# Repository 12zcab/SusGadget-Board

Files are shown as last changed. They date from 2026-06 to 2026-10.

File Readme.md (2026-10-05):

## SusGadget

IMG_20260813_192945 (2)
A hack ducky which can maybe do some questionable stuff to your computer or maybe it’s just a sweet little game who knows!
<br>
<br>

## Table of contents
- [Zine page](#Zine)
- [Images](#Images)
- [What is this](#What-is-this)
- [Why I made this](#Why-I-made-this)
- [Parts required](#Parts-required)
- [How to make it yourself](#How-to-make-it-yourself)

<br>
<br>
Huge thanks to Raghav who helped me polish the project and improved many design flaws and zine design :) 

## Zine
Zine

## Youtube Demo

[Watch here!](https://youtu.be/1S0NnBTiFww?si=1X6zqkv0NfYqutrI)

## Images

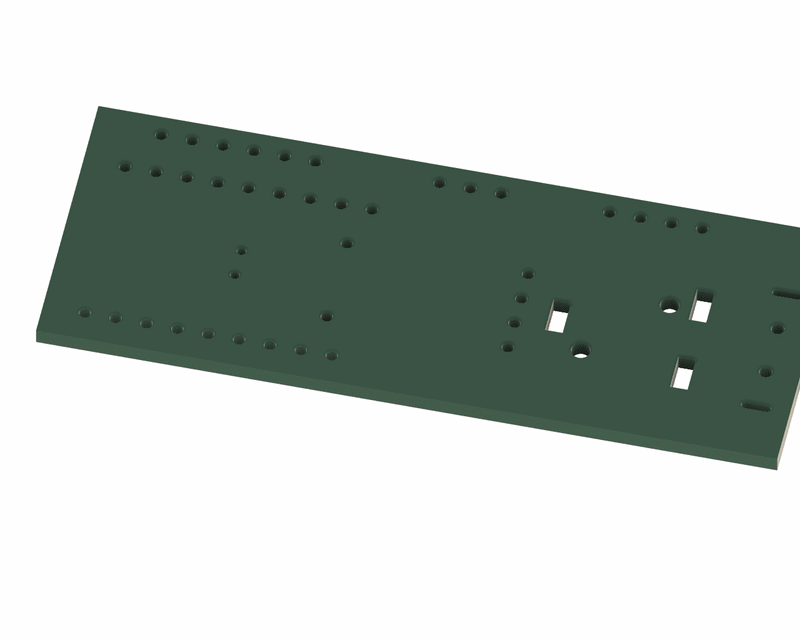
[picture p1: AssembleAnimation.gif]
Assemble







design (1)
pcbf
routing (1)

<br>
<br>

## What is this

This is a esp32 S3 supermini based Hackducky, with an OLED display, a joystick and a potentiometer which can be used to execute commands on your friend's computer to prank them or maybe just it as a mini display for timers, temperatures or any other stats, the possibilities are endless! !
it also has a potentiometer and a buzzer so u can may be make some weird beep noise that changes its pitch while u spin the potentiometer and communicate with aliens (welp, who knows?)
Definitely a cool gadget and definitely sus enough :D
<br>
<br>

## Why I made this :|
Humm idk this is like what people think electronic nerds will make : |
(Actually i wanna try to plug in this usb and tell my friend this is just a oled small screen to monitor his computer's temperature then shutdown his computer with Alt+F4+Enter while he plays Roblox :DDDDD)

## Parts required
 1. A 0.91 inch Oled for Display
 2. A Potentiometer for Analog Input
 3. A Joystick Module Connecter
 4. A RGB WS2812 LED on board
 5. A USB-A with CH340 on board serial interface (and for power)
 6. Extend IO Ports (GPIO,I2C)
 7. 5-Way Joy-Stick like Switch
 8. a buzzer :D

## How to make it yourself
 <h3> 1. Acquire parts </h3>
- Navigate to the BOM in the repository and buy the listed parts. <br>
- 3D print the case by acquiring stl files from the 3de print folder in the repository. <br>
- Order PCB by using the gerber files provided in the repository. <br>
 
 <h3> 2. Assembly </h3>
 - Solder all the components on the PCB. <br>
 - Put the soldered PCB in the case. <br>
  
 <h3> 3. Firmware setup </h3>

 - Connect your device to the esp 32 <br>
 - Download the firmware files from the repo <br>
 - Load the firmware <br>

<h3> 4. (most imp step) </h3>
- prank your friends <br>
- have fun  <br>

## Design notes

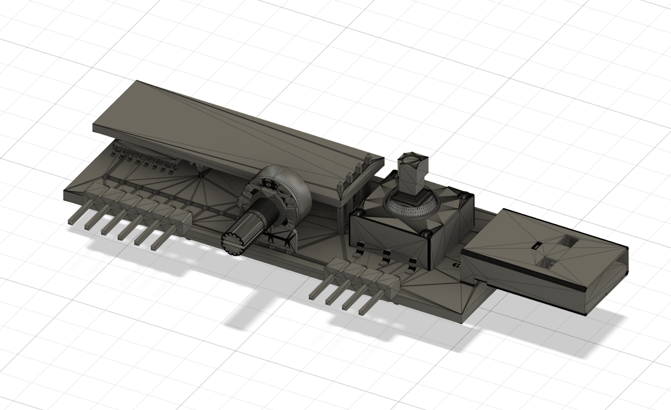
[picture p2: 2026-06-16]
Images/3Ddesign.png

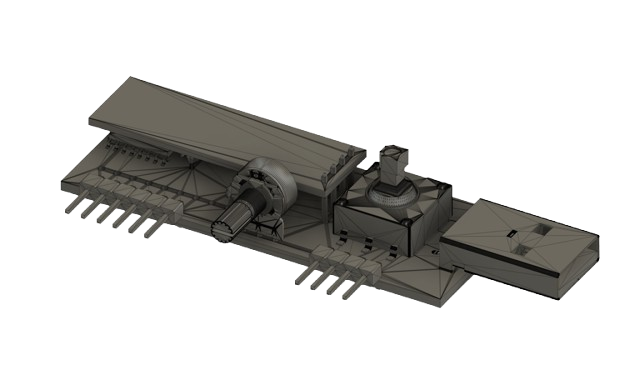
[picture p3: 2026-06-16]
Images/3Ddesign-removebg-preview.png

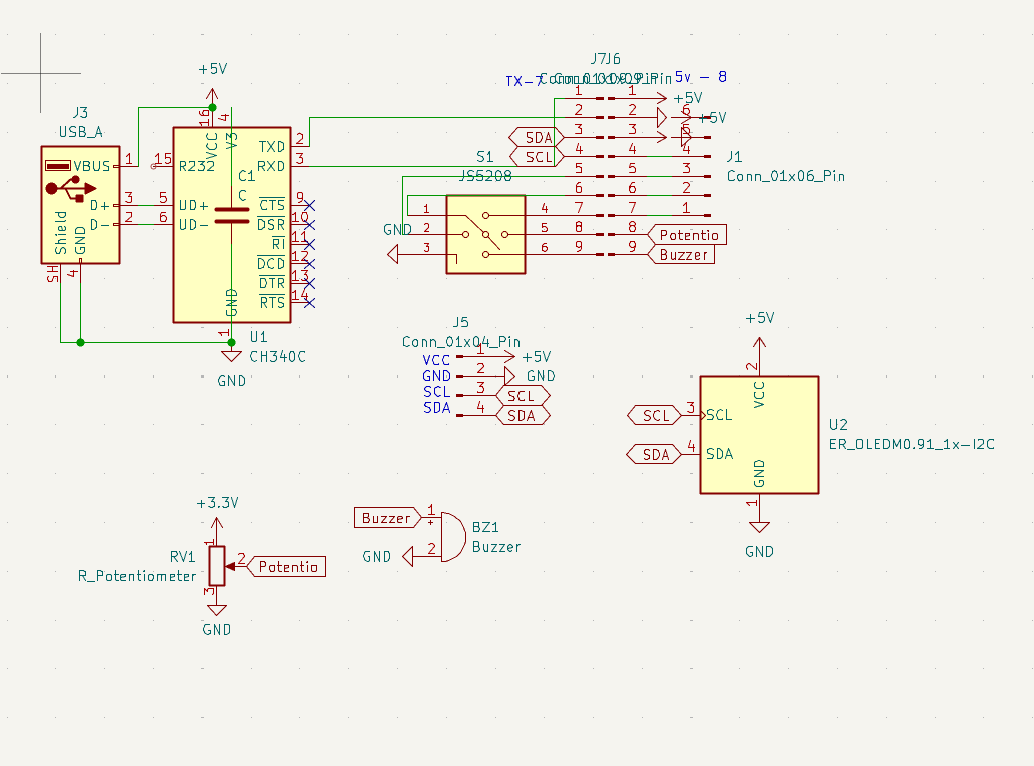
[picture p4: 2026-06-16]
Images/design (1).png

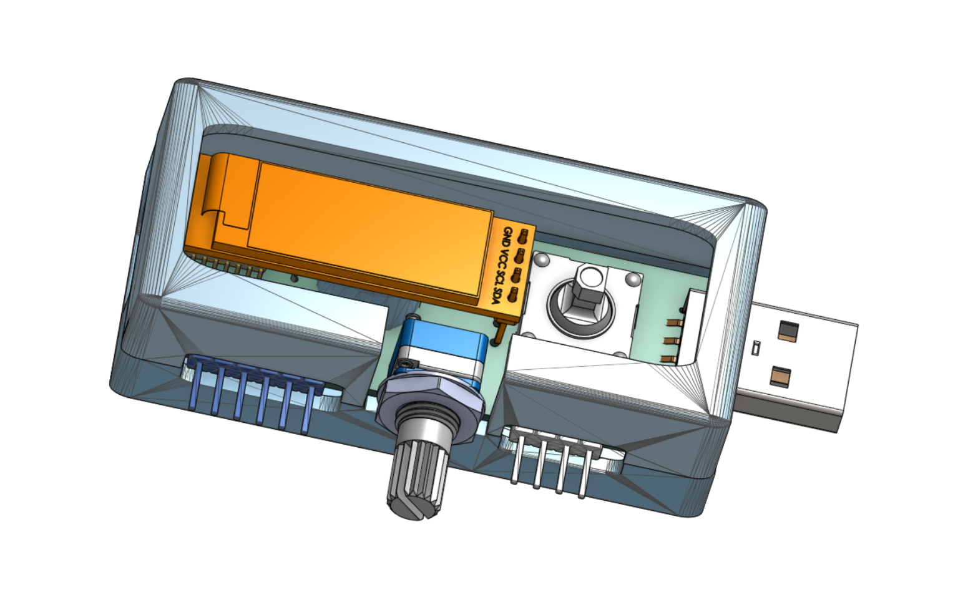
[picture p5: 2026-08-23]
Images/Screenshot 2026-08-23 152553.png

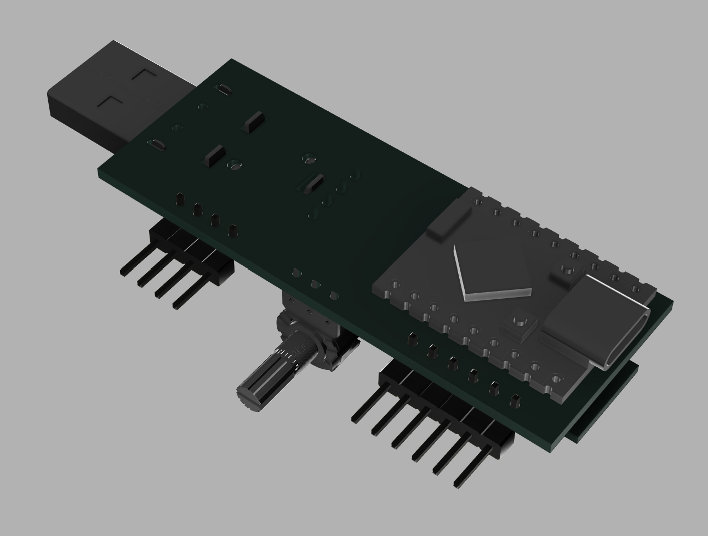
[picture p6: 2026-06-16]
Images/3DB.png

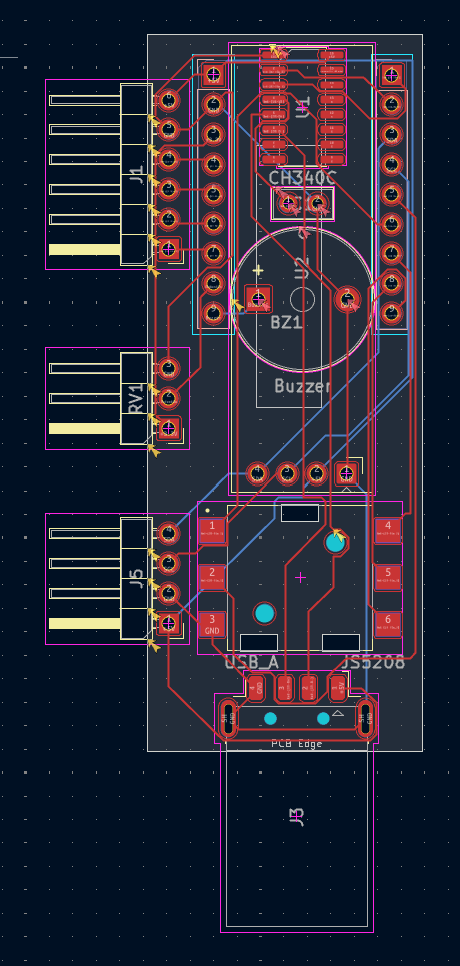
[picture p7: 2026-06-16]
Images/routing (1).png

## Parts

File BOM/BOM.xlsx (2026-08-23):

Name | Link | Quantity | QT Price | RMBPrice | USDPrice
ESP32 S3 Supermini | https://item.taobao.com/item.htm?id=980496057690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 | 1 | 14.9 | 14.9 | 2.235
JS5208 | https://item.taobao.com/item.htm?id=739043147728 | 1 | 2.2 | 2.2 | 0.33
104 Capacitor | https://detail.tmall.com/item.htm?ali_trackid=318_c9a42c10e288c0737574497ed4e334d1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 | 1 | Negligible | Negligible | 0
I2C Oled 0.91inch | https://item.taobao.com/item.htm?id=799718292351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 | 1 | 8 | 8 | 1.2
Potentiometer | https://detail.tmall.com/item.htm?id=611352518150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 | 1 | 5.5 | 5.5 | 0.825
USB-A Male SMD | https://item.taobao.com/item.htm?id=1003164355210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 | 1 | 2.19 | 2.19 | 0.3285
CH340C | https://item.taobao.com/item.htm?id=572355836370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 | 1 | 2.31 | 2.31 | 0.3465
Estimated PCB cost |  |  |  |  | 10
Including PinHeaders and PinSocket |  |  |  |  | 0.5
Also USB Convertors are required(Not Essential) |  |  |  |  | 0
Sum Up |  |  |  |  | 15.765

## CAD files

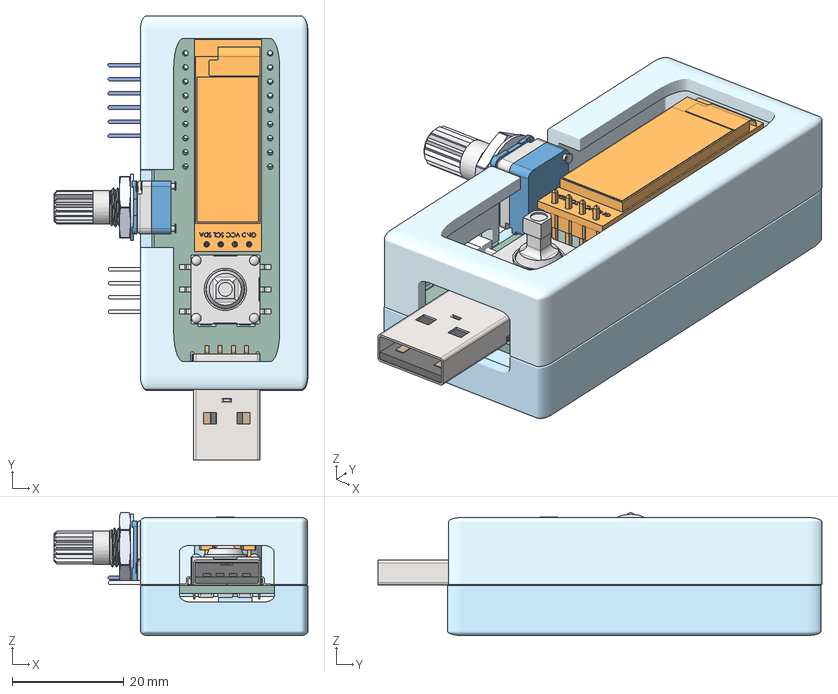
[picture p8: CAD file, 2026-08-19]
3D/Final_assembly_sus_gadget.step
45.5 x 79.6 x 22.1 mm
RK097x-Base-Rivets-ShaftKC x 6
susGadget_PCB
Ressalto-extrus�o10
Cut-Extrude15
RK097x-Housing1 x 4
RK097x-Cover

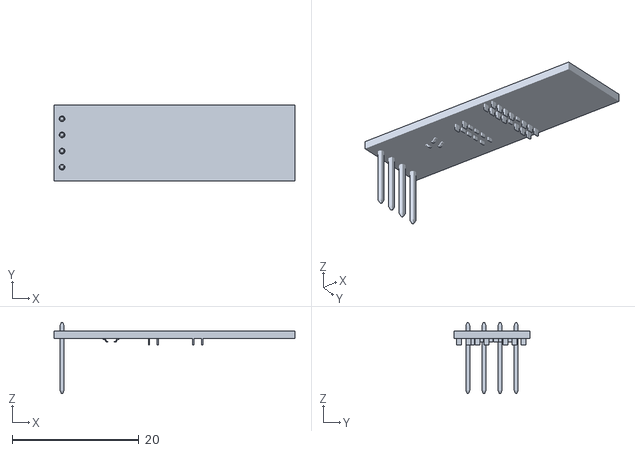
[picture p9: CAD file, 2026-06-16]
3D/OLED 128 x 32 Display Assembly.stl
38.0 x 12.0 x 11.2

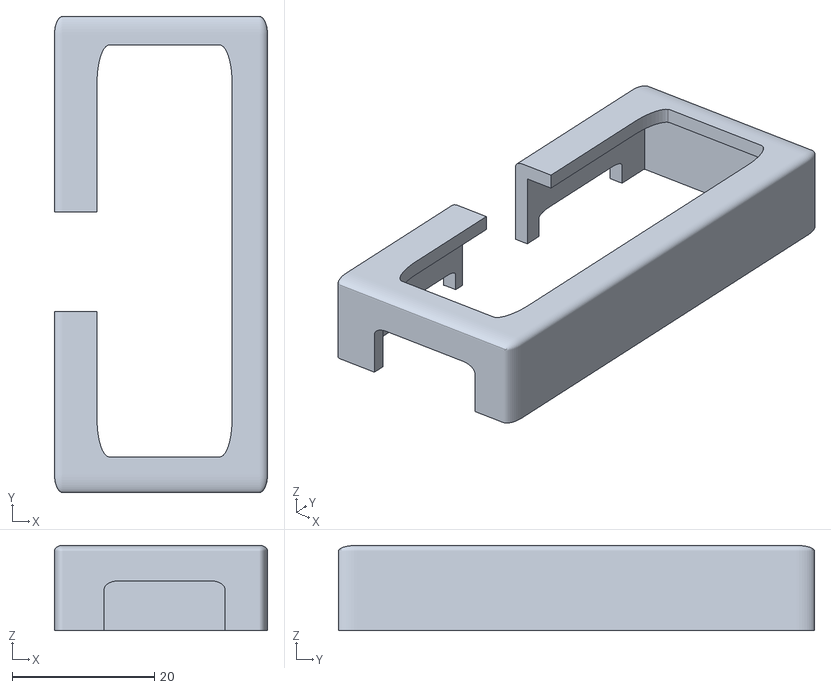
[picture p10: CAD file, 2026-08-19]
3D/NewUp.stl
30.0 x 67.0 x 12.0

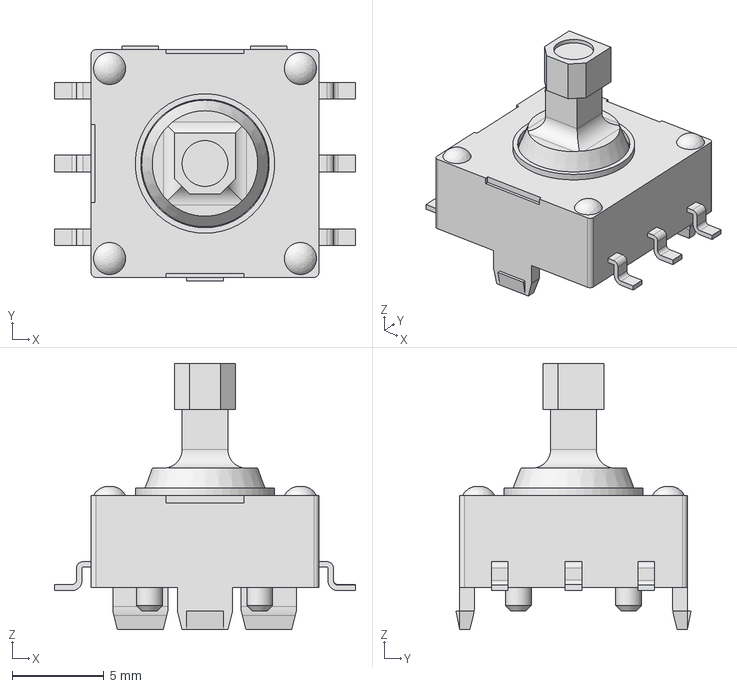
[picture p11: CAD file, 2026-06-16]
JS5208/JS5208.step
16.4 x 12.8 x 14.5 mm

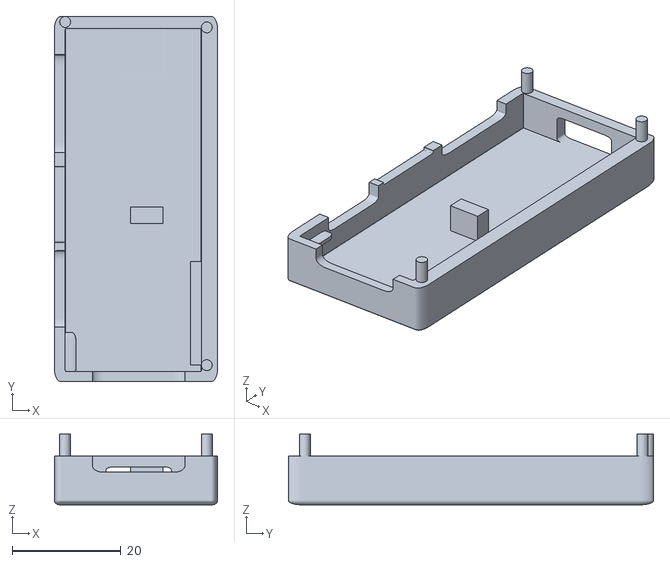
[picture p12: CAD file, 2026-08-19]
3D/NewBottom.stl
30.0 x 67.0 x 13.0

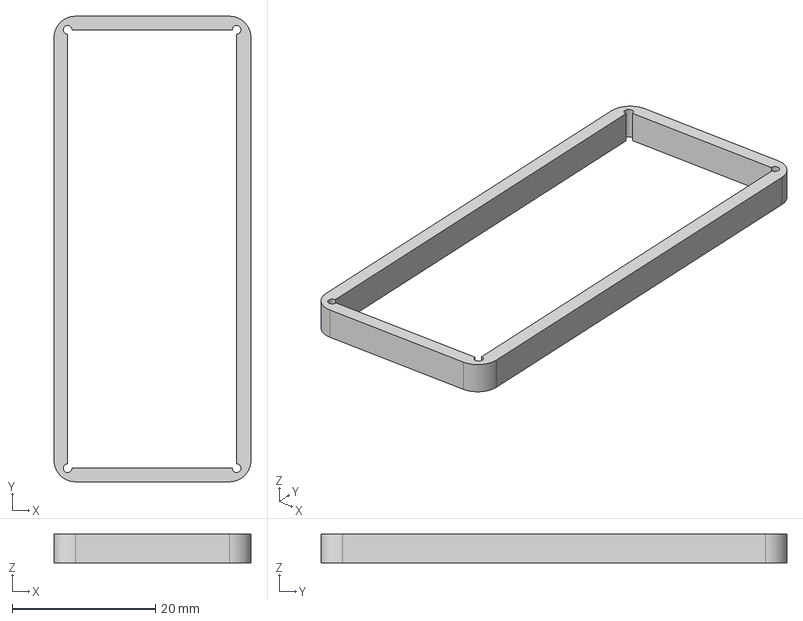
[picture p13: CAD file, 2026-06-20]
3D/CaseCap.step
27.5 x 65.0 x 4.00 mm

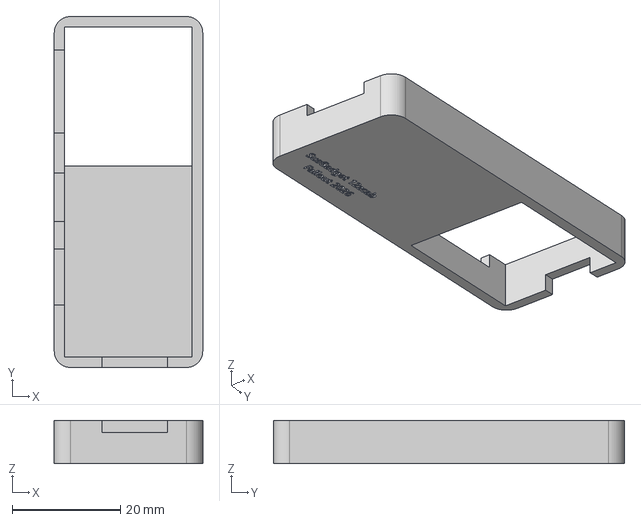
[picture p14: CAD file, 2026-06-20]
3D/Case.step
27.5 x 65.0 x 8.00 mm

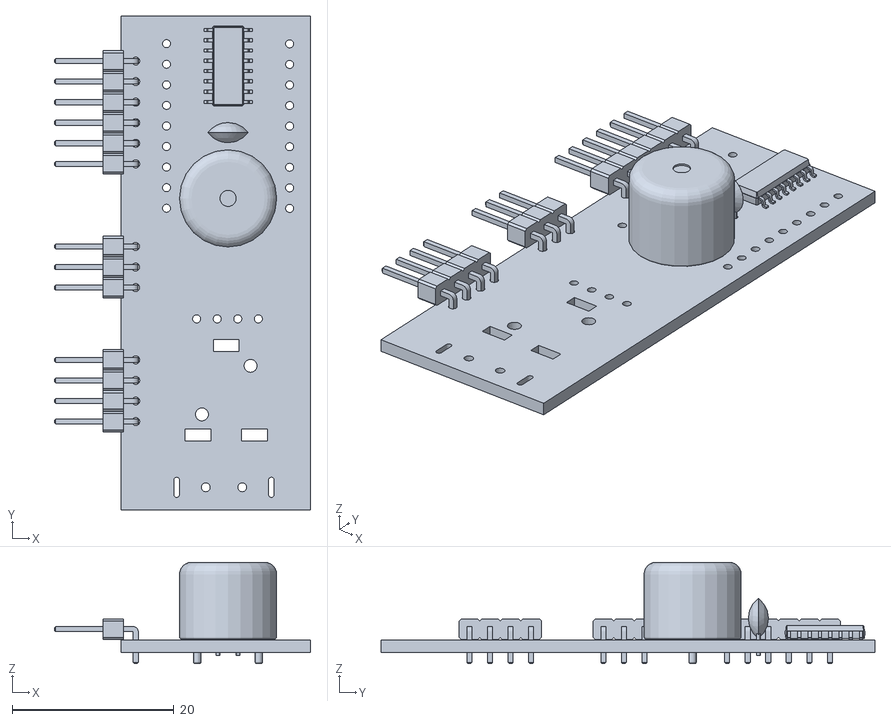
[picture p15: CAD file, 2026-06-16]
3D/pcb_with_com.stl
31.7 x 61.0 x 12.5

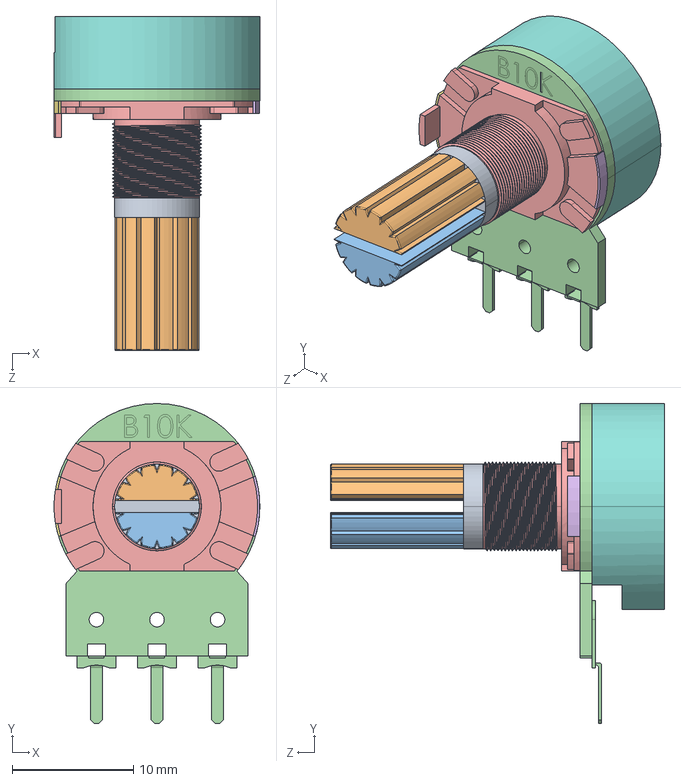
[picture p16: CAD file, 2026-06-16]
3D/PotentiometerB10K.STEP
17.0 x 26.4 x 27.6 mm

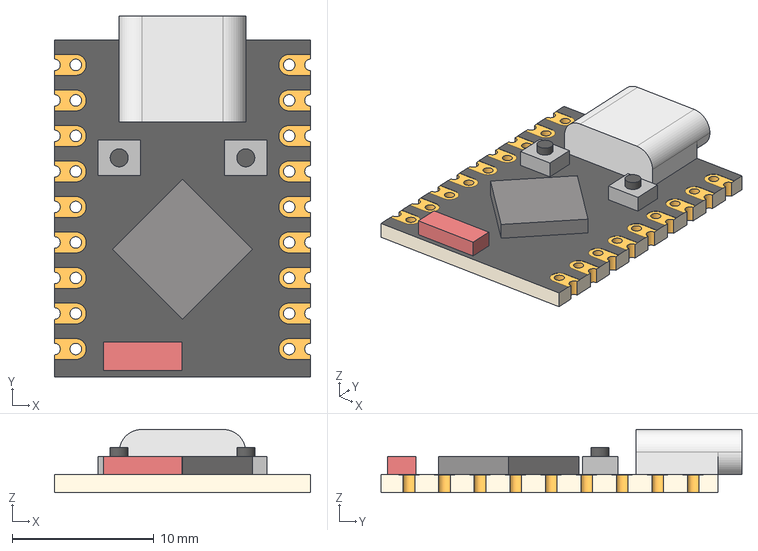
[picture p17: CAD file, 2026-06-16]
3D/ESP32S3 Super Mini.step
18.0 x 25.4 x 4.45 mm

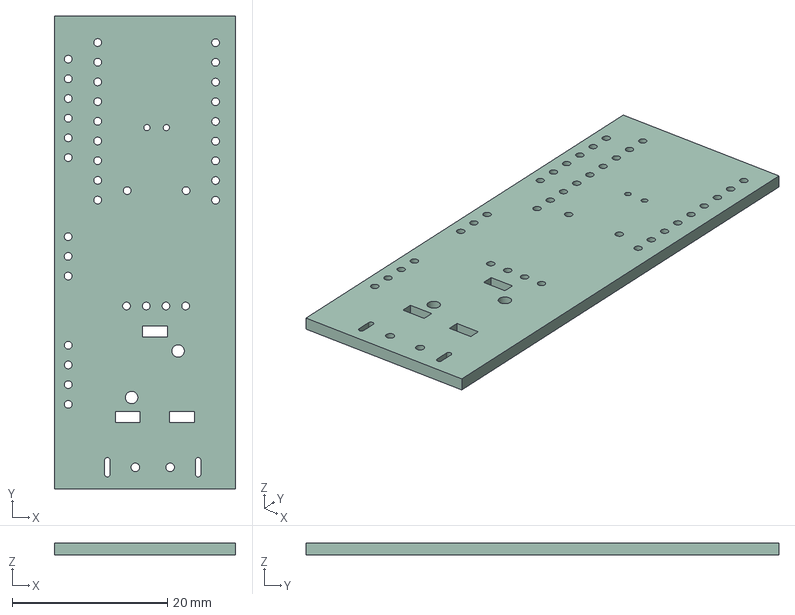
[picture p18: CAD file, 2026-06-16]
3D/pcb.step
23.4 x 61.0 x 1.51 mm

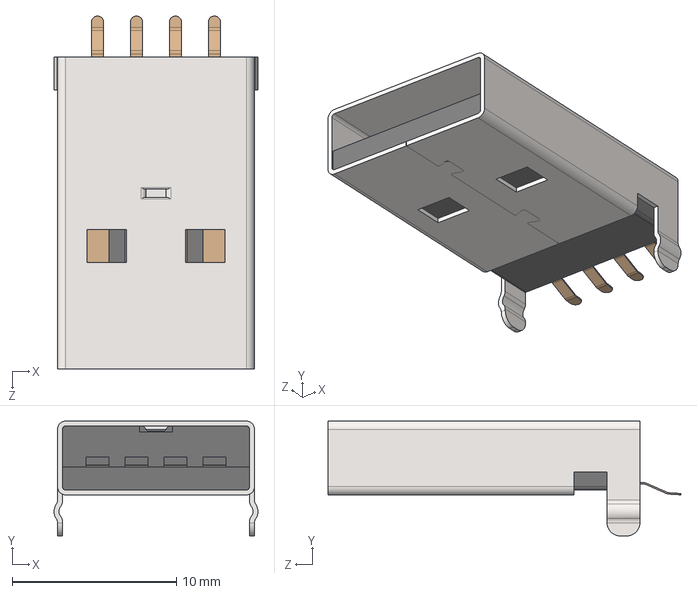
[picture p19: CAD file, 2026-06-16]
3D/USB Connector Type A male, SMT.STEP
12.4 x 7.00 x 21.5 mm

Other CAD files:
3D/ESP32S3 Super Mini.stl
3D/JS5208.stl
3D/PotentiometerB10K.stl
3D/USB Connector Type A male, SMT.stl
3D/pcb.stl

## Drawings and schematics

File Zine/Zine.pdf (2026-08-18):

# SUS GADGET

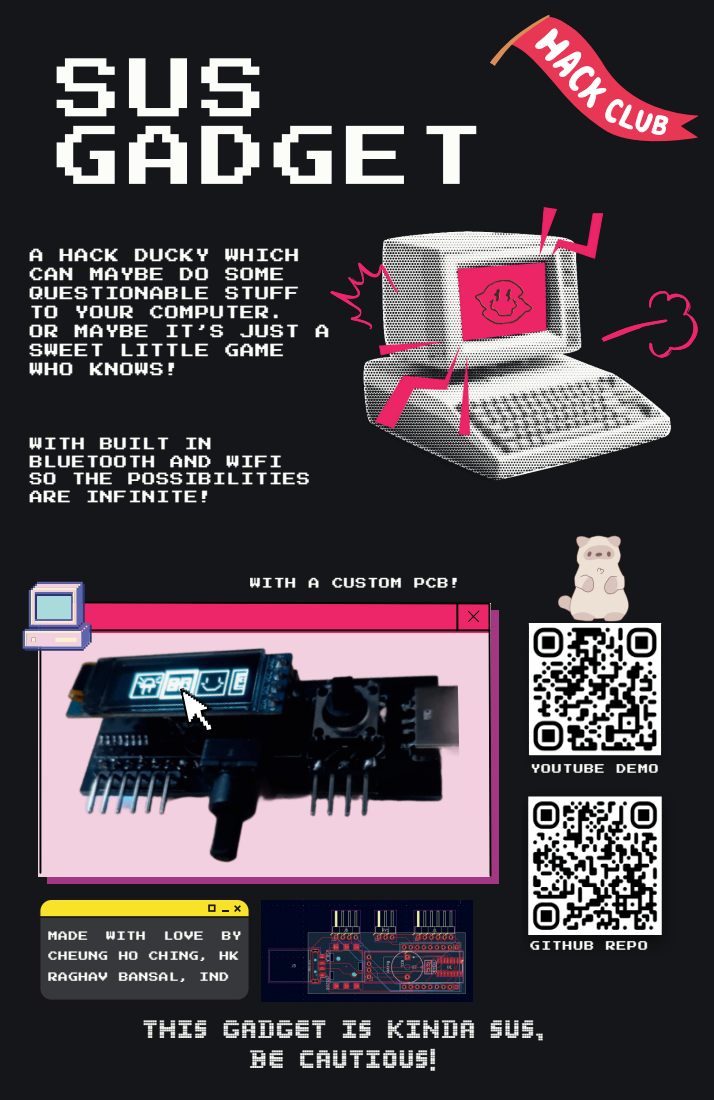
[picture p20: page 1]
YOUTUBE DEMO; GITHUB REPO; MADE; WITH; LOVE

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

WITH BUILT IN
BLUETOOTH AND WIFI
SO THE POSSIBILITIES
ARE INFINITE!

WITH A CUSTOM PCB!

CHEUNG HO CHING, HK
RAGHAV BANSAL, IND
This gadget is kinda sus,
be cautious!

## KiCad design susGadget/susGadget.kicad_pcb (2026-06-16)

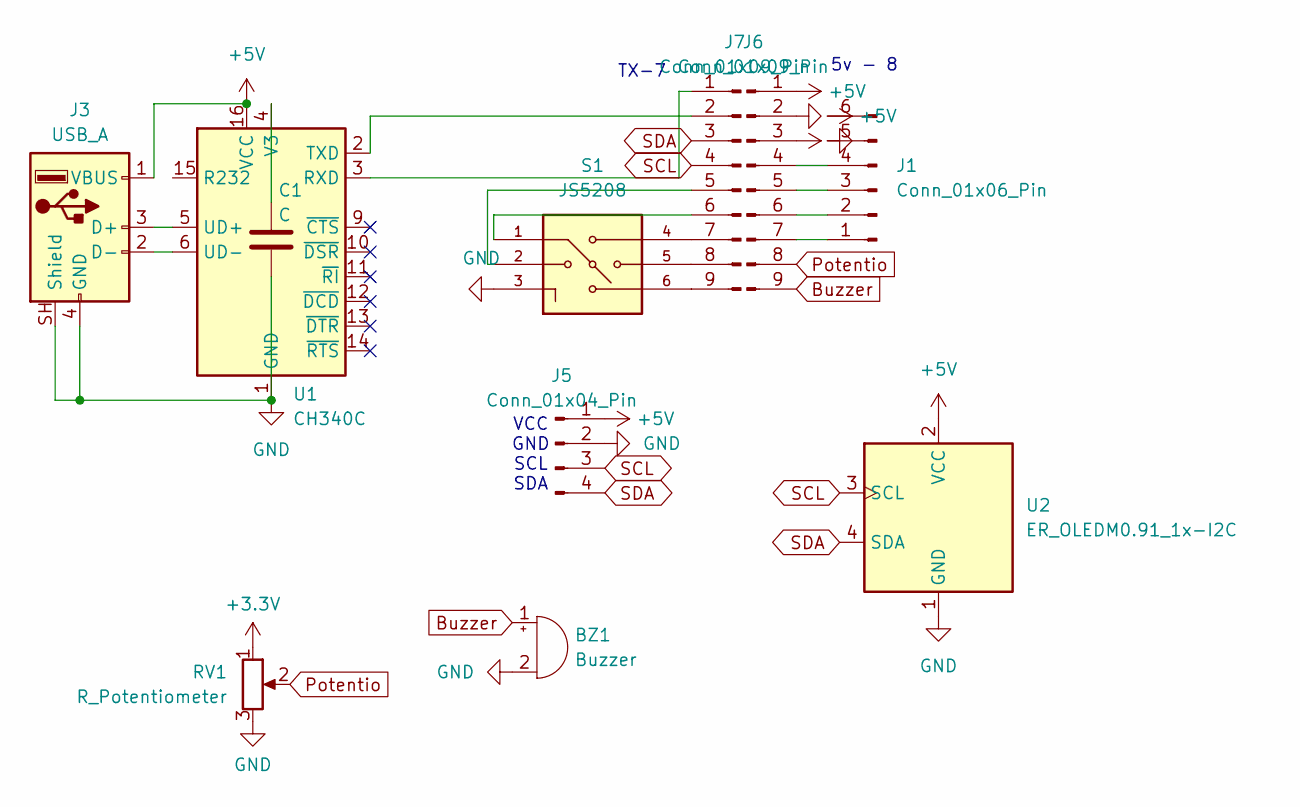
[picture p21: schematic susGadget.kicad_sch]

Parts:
BZ1: Buzzer; Buzzer_12x9.5RM7.6
C1: C; C_Disc_D5.0mm_W2.5mm_P2.50mm
J1: Conn_01x06_Pin; PinHeader_1x06_P2.54mm_Horizontal
J3: USB_A; USB_A_Molex_48037-2200_Horizontal
J5: Conn_01x04_Pin; PinHeader_1x04_P2.54mm_Horizontal
J6, J7: Conn_01x09_Pin; PinSocket_1x09_P2.54mm_Vertical
RV1: R_Potentiometer; PinHeader_1x03_P2.54mm_Horizontal
S1: JS5208; SW_JS5208; PARTREV D
U1: CH340C; SOIC-16_3.9x9.9mm_P1.27mm
U2: ER_OLEDM0.91_1x-I2C

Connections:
+3.3V: J6.3, RV1.1
+5V: J1.6, J3.1 (VBUS), J5.1, J6.1, U1.16 (VCC), U2.2 (VCC)
Buzzer: BZ1.1 (+), J6.9
GND: BZ1.2 (-), C1.2, J1.5, J3.4 (GND), J3.SH (Shield), J5.2, J6.2, RV1.3, S1.3, U1.1 (GND), U2.1 (GND)
unnamed: J1.1, J6.7
unnamed: J1.2, J6.6
unnamed: J1.3, J6.5
unnamed: J1.4, J6.4
unnamed: J3.3 (D+), U1.5 (UD+)
unnamed: J3.2 (D-), U1.6 (UD-)
unnamed: J7.1, U1.3 (RXD)
unnamed: J7.2, U1.2 (TXD)
unnamed: J7.5, S1.2
unnamed: J7.6, S1.1
unnamed: J7.7, S1.4
unnamed: J7.8, S1.5
unnamed: J7.9, S1.6
unnamed: C1.1, U1.4 (V3)
Potentio: J6.8, RV1.2
SCL: J5.3, J7.4, U2.3 (SCL)
SDA: J5.4, J7.3, U2.4 (SDA)

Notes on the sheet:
TX-7
5v - 8
VCC GND SCL SDA

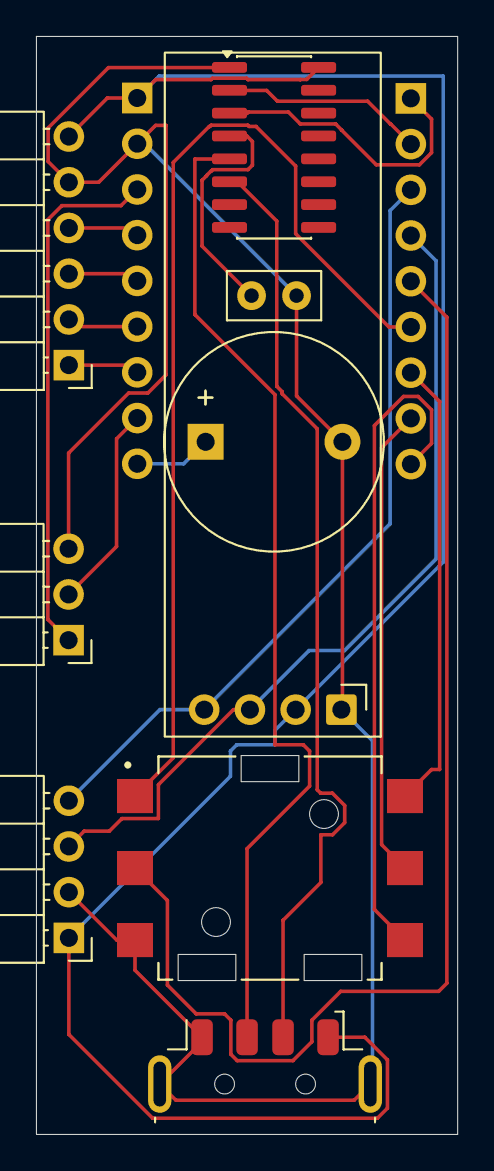
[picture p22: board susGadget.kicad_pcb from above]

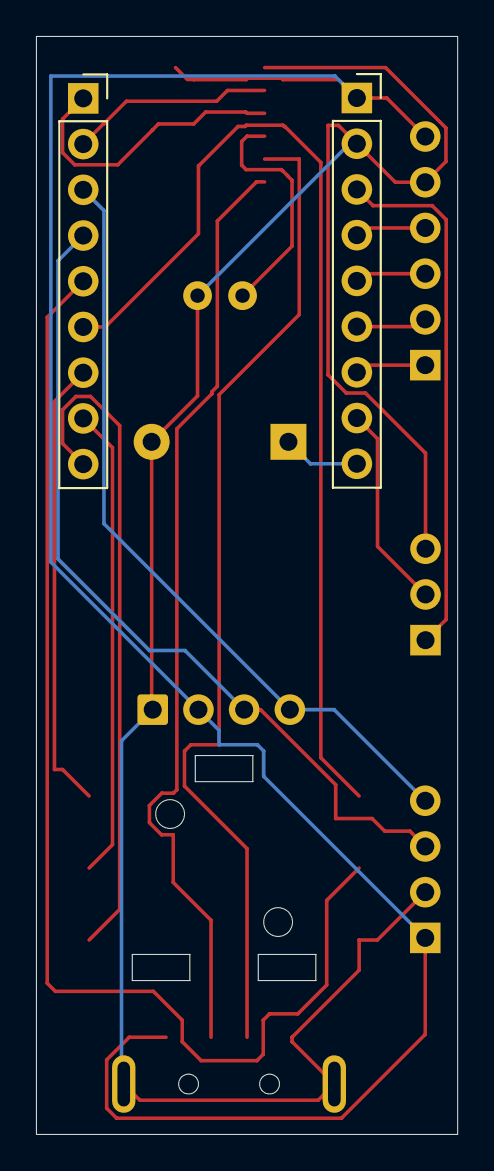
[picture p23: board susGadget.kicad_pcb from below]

Board: 2 copper layers, 23.4 x 61.0 mm, 11 parts (2 on the bottom side), 21 nets.

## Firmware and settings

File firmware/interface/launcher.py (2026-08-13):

import sys
import board
import digitalio
import re
def run_independent_app(app_path):
    print(f"[Launcher] Preparing Line-by-Line Sandbox (With Direct _end_ Check) for: {app_path}")
    
    try:
        with open(app_path, "r") as f:
            raw_code = f.read()
    except Exception:
        print(f"[Launcher] Error: Cannot find app at {app_path}")
        return

    function_text_injection = """
import board, digitalio, sys

def _Launcher_check_():
    try:
        with digitalio.DigitalInOut(board.IO0) as btn:
            btn.direction = digitalio.Direction.INPUT
            btn.pull = digitalio.Pull.UP
            if not btn.value:
                print("\\n[Launcher Check] Escape Button detected!")
                try:
                    if '_end_' in globals() or '_end_' in locals():
                        print("[Launcher Check] Directly calling App native _end_()...")
                        globals().get('_end_', locals().get('_end_'))()
                except Exception as ce:
                    print("[Launcher Check] App _end_() execution failed:", ce)
                raise KeyboardInterrupt("App terminated after direct end() call")
    except KeyboardInterrupt:
        raise
    except Exception:
        pass
"""

    loop_pattern = re.compile(r'^([ \t]*)(while|for)\s+(.+):')

    lines = raw_code.split('\n')
    modified_lines = []

    for line in lines:
        modified_lines.append(line)
        match = loop_pattern.match(line)
        if match:
            indent = match.group(1)
            modified_lines.append(f"{indent}    _Launcher_check_()")

    modified_code = '\n'.join(modified_lines)
    final_executable_code = function_text_injection + "\n" + modified_code

    print("[Launcher] Direct end() Call Injection Result:")
    print("----------------------------------------")
    print(final_executable_code)
    print("----------------------------------------")

    app_folder = "/".join(app_path.split("/")[:-1])
    if app_folder == "":
        app_folder = "/"

    if "/interface" not in sys.path:
        sys.path.append("/interface")

    path_was_added = False
    if app_folder not in sys.path:
        sys.path.insert(0, app_folder)
        path_was_added = True

    app_globals = {
        "__name__": "__main__",
        "__file__": app_path,
        "__path__": app_folder
    }

    try:
        exec(final_executable_code, app_globals)
        print("[Launcher] App finished execution naturally.")
    except KeyboardInterrupt:
        print("[Launcher] App successfully destroyed after direct exit cleanup.")
    except Exception as e:
        print(f"[Launcher] App crashed with error: {e}")
    finally:
        if path_was_added and app_folder in sys.path:
            sys.path.remove(app_folder)
            
        for key in list(sys.modules.keys()):
            try:
                mod = sys.modules[key]
                if hasattr(mod, '__file__') and mod.__file__ and app_folder in mod.__file__:
                    del sys.modules[key]
            except Exception:
                pass
                
        app_globals.clear()
        print("[Launcher] Sandbox cleaned. Back to launch.py GUI.\n")

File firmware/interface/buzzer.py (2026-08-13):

import time
import board
import pwmio
global buzzer
def init():
    global buzzer
    buzzer = pwmio.PWMOut(board.IO8, frequency=1000, duty_cycle=0, variable_frequency=True)
    print("Buzzer Initialized")
def play_tone(frequency, duration):
    global buzzer
    buzzer.frequency = frequency
    buzzer.duty_cycle = 32768
    time.sleep(duration)
    buzzer.duty_cycle = 0
def active():
    global buzzer
    buzzer.duty_cycle = 32768
def deactive():
    global buzzer
    buzzer.duty_cycle = 0
def freq(fre):
    global buzzer
    buzzer.frequency = fre
def play_series(frequencies, durations):
    for frequency,duration in zip(frequencies, durations):
        if frequency == 0:
            time.sleep(duration)
        else:
            play_tone(frequency,duration)
init()

#play_series([659, 622, 659, 622, 659, 494, 587, 523, 440, 0, 262, 330, 440, 494, 0, 330, 494, 523, 659], [0.3, 0.3, 0.3, 0.3, 0.3, 0.3, 0.3, 0.3, 0.6, 0.2, 0.3, 0.3, 0.3, 0.6, 0.2, 0.3, 0.3, 0.3, 0.6])
#hehe an easter egg
# 12zcab 4/Aug/2026 01:17a.m.

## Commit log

2026-08-19 Rename Fantastic Blorr-Migelo (1).stl to NewBottom.stl
    [NewBottom.stl]
2026-08-19 Rename topcase-sus (1).stl to NewUp.stl
    [NewUp.stl]
2026-08-23 Add BOM file with component details and pricing
2026-08-23 Update BOM
2026-08-23 Add BOM.me file
2026-08-23 Rename BOM (1).csv to BOM.csv
    [BOM.csv]
2026-08-23 Revise Readme.md with project information and images
    Updated Readme.md to include project details, images, assembly instructions, and logs.
2026-08-23 Revise Readme.md with project information and images
    Updated the Readme.md to include project details, images, assembly instructions, and logs.
